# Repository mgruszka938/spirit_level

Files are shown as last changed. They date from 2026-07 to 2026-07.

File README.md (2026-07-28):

# Digital Spirit Level 

A compact, battery-powered digital level built with an STM32 microcontroller and an OLED screen. This project was developed as part of the "Sensors in Embedded Applications" course at AGH University of Science and Technology.

## Project Overview
The goal was to design a highly portable, precise digital measuring tool. The device features a USB-C port for charging, built-in Li-Ion battery support, and a three-button interface for resetting or zeroing the position. 

## Hardware & Components
The component selection prioritizes low power consumption, accuracy, and a small physical footprint.

* **Microcontroller:** STM32L433 (ARM Cortex-M4) - Picked for its low power usage and built-in FPU (Floating Point Unit) for faster angle calculations. It also runs without an external crystal oscillator, saving board space.
* **IMU Sensor:** LSM6DSO - A 6-axis accelerometer/gyroscope chosen for its high stability and low noise. Communicates over I2C.
* **Power Management:** MCP73871 - A load-sharing charge controller. It allows the device to be used normally while the Li-Ion battery is charging.
* **Display:** 0.96-inch OLED - A small, high-contrast I2C screen for the user interface.
* **Connectivity:** USB-C (charging) and SWD (programming).

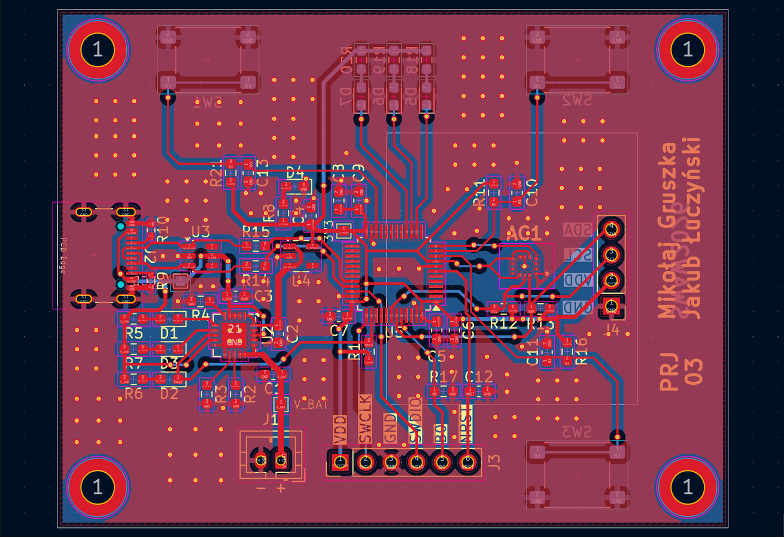
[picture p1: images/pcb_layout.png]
PCB Layout


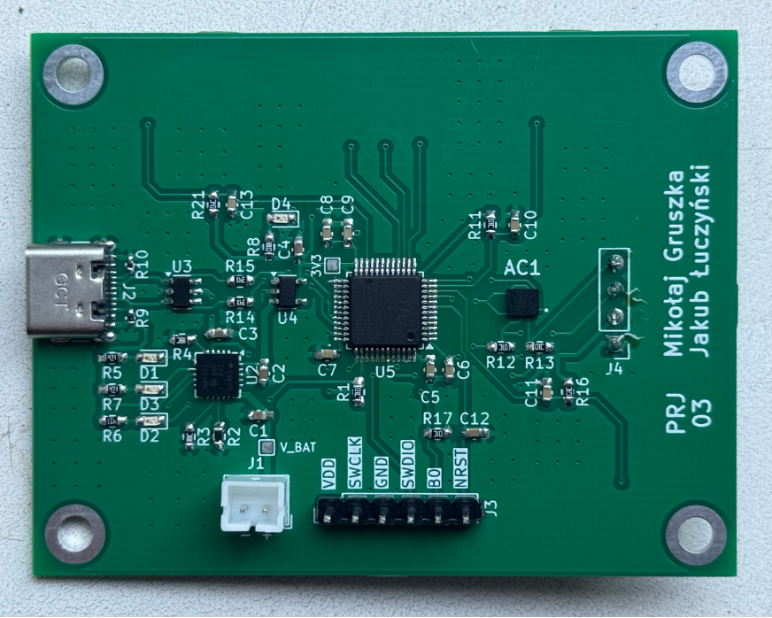
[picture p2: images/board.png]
3D Render


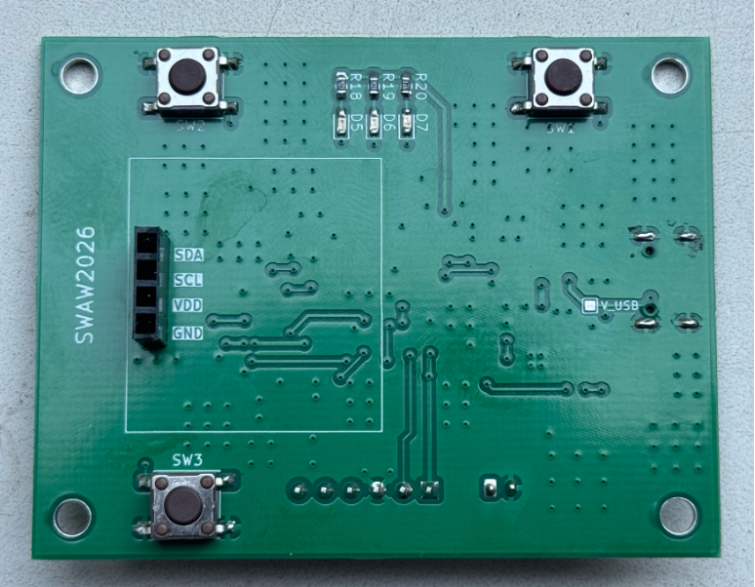
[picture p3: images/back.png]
Back


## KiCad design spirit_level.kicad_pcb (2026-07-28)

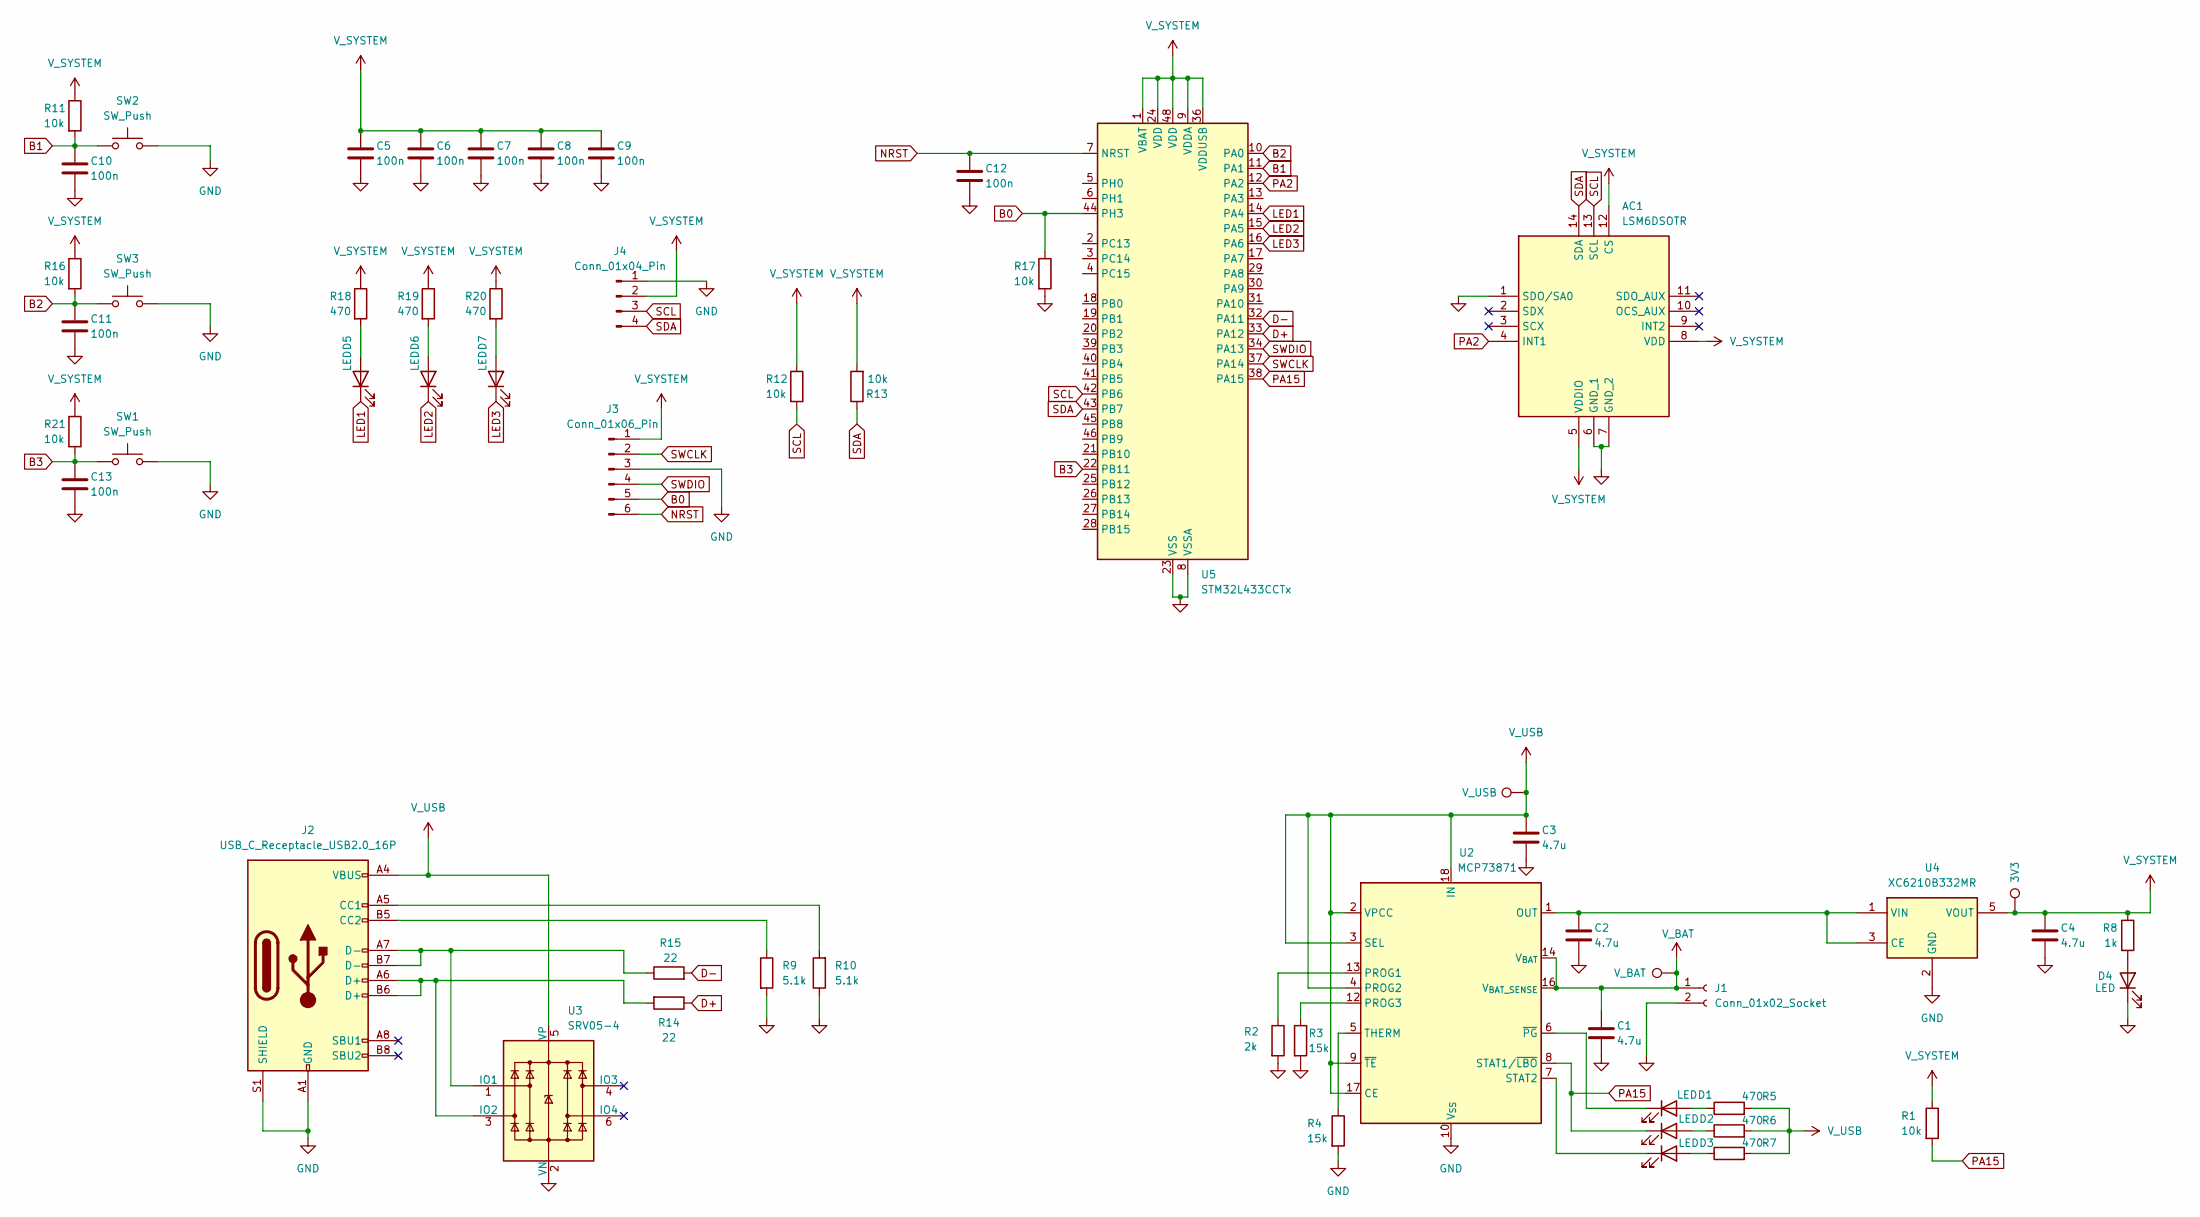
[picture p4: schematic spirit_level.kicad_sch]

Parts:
3V3: TestPoint_Pad_1.0x1.0mm
AC1: LSM6DSOTR; Mouser Part Number 511-LSM6DSOTR
C1, C2, C3, C4: 4.7u; C_0603_1608Metric_Pad1.08x0.95mm_HandSolder
C5, C6, C7, C8, C9, C10, C11, C12, C13: 100n; C_0603_1608Metric_Pad1.08x0.95mm_HandSolder
D1, D2, D3, D4, D5, D6, D7: LED; D_0603_1608Metric_Pad1.05x0.95mm_HandSolder
J1: Conn_01x02_Socket; JST_PH_B2B-PH-K_1x02_P2.00mm_Vertical
J2: USB_C_Receptacle_USB2.0_16P; USB_C_Receptacle_GCT_USB4105-xx-A_16P_TopMnt_Horizontal
J3: Conn_01x06_Pin; PinHeader_1x06_P2.54mm_Vertical
J4: Conn_01x04_Pin; PinHeader_1x04_P2.54mm_Vertical
R1, R11, R12, R13, R16, R17, R21: 10k; R_0603_1608Metric_Pad0.98x0.95mm_HandSolder
R2: 2k; R_0603_1608Metric_Pad0.98x0.95mm_HandSolder
R3, R4: 15k; R_0603_1608Metric_Pad0.98x0.95mm_HandSolder
R5, R6, R7, R18, R19, R20: 470; R_0603_1608Metric_Pad0.98x0.95mm_HandSolder
R8: 1k; R_0603_1608Metric_Pad0.98x0.95mm_HandSolder
R9, R10: 5.1k; R_0402_1005Metric_Pad0.72x0.64mm_HandSolder
R14, R15: 22; R_0603_1608Metric_Pad0.98x0.95mm_HandSolder
SW1, SW2, SW3: SW_Push; SW_SPST_PTS645Sx43SMTR92
U2: MCP73871; QFN-20-1EP_4x4mm_P0.5mm_EP2.5x2.5mm
U3: SRV05-4; SOT-23-6
U4: XC6210B332MR; SOT-23-5
U5: STM32L433CCTx; LQFP-48_7x7mm_P0.5mm
V_BAT: TestPoint_Pad_1.0x1.0mm
V_USB: TestPoint_Pad_1.0x1.0mm

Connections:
B0: J3.5, R17.1, U5.44 (PH3)
B1: C10.1, R11.2, SW2.1, U5.11 (PA1)
B2: C11.1, R16.2, SW3.1, U5.10 (PA0)
B3: C13.1, R21.2, SW1.1, U5.22 (PB11)
D+: R14.1, U5.33 (PA12)
D-: R15.2, U5.32 (PA11)
GND: AC1.1 (SDO/SA0), AC1.6 (GND_1), AC1.7 (GND_2), C1.2, C2.2, C3.2, C4.2, C5.2, C6.2, C7.2, C8.2, C9.2, C10.2, C11.2, C12.2, C13.2, D4.1 (K), J1.2, J2.A1 (GND), J2.A12 (GND), J2.B1 (GND), J2.B12 (GND), J2.S1 (SHIELD), J3.3, J4.1, R2.2, R3.2, R4.2, R9.2, R10.1, R17.2, SW1.2, SW2.2, SW3.2, U2.10 (V_{SS}), U2.11 (V_{SS}), U2.21 (V_{SS}), U3.2 (VN), U4.2 (GND), U5.8 (VSSA), U5.23 (VSS), U5.35 (VSS), U5.47 (VSS)
LED1: D5.1 (K), U5.14 (PA4)
LED2: D6.1 (K), U5.15 (PA5)
LED3: D7.1 (K), U5.16 (PA6)
NRST: C12.1, J3.6, U5.7 (NRST)
unnamed: D1.2 (A), R5.1
unnamed: D1.1 (K), U2.6 (~PG)
unnamed: D2.2 (A), R6.1
unnamed: D3.2 (A), R7.1
unnamed: D3.1 (K), U2.7 (STAT2)
unnamed: D4.2 (A), R8.2
unnamed: D5.2 (A), R18.2
unnamed: D6.2 (A), R19.2
unnamed: D7.2 (A), R20.2
unnamed: J2.A5 (CC1), R10.2
unnamed: J2.B5 (CC2), R9.1
unnamed: R2.1, U2.13 (PROG1)
unnamed: R3.1, U2.12 (PROG3)
unnamed: R4.1, U2.5 (THERM)
unnamed: J2.A7 (D-), J2.B7 (D-), R15.1, U3.1 (IO1)
unnamed: J2.A6 (D+), J2.B6 (D+), R14.2, U3.3 (IO2)
unnamed: C2.1, U2.1 (OUT), U2.20 (OUT), U4.1 (VIN), U4.3 (CE)
PA2: AC1.4 (INT1), U5.12 (PA2)
PA15: D2.1 (K), R1.2, U2.8 (STAT1/~LBO), U5.38 (PA15)
SCL: AC1.13 (SCL), J4.3, R12.2, U5.42 (PB6)
SDA: AC1.14 (SDA), J4.4, R13.1, U5.43 (PB7)
SWCLK: J3.2, U5.37 (PA14)
SWDIO: J3.4, U5.34 (PA13)
V_BAT: C1.1, J1.1, U2.14 (V_{BAT}), U2.15 (V_{BAT}), U2.16 (V_{BAT_SENSE}), V_BAT.1
V_SYSTEM: 3V3.1, AC1.5 (VDDIO), AC1.8 (VDD), AC1.12 (CS), C4.1, C5.1, C6.1, C7.1, C8.1, C9.1, J3.1, J4.2, R1.1, R8.1, R11.1, R12.1, R13.2, R16.1, R18.1, R19.1, R20.1, R21.1, U4.5 (VOUT), U5.1 (VBAT), U5.9 (VDDA), U5.24 (VDD), U5.36 (VDDUSB), U5.48 (VDD)
V_USB: C3.1, J2.A4 (VBUS), J2.A9 (VBUS), J2.B4 (VBUS), J2.B9 (VBUS), R5.2, R6.2, R7.2, U2.2 (VPCC), U2.3 (SEL), U2.4 (PROG2), U2.9 (~TE), U2.17 (CE), U2.18 (IN), U2.19 (IN), U3.5 (VP), V_USB.1

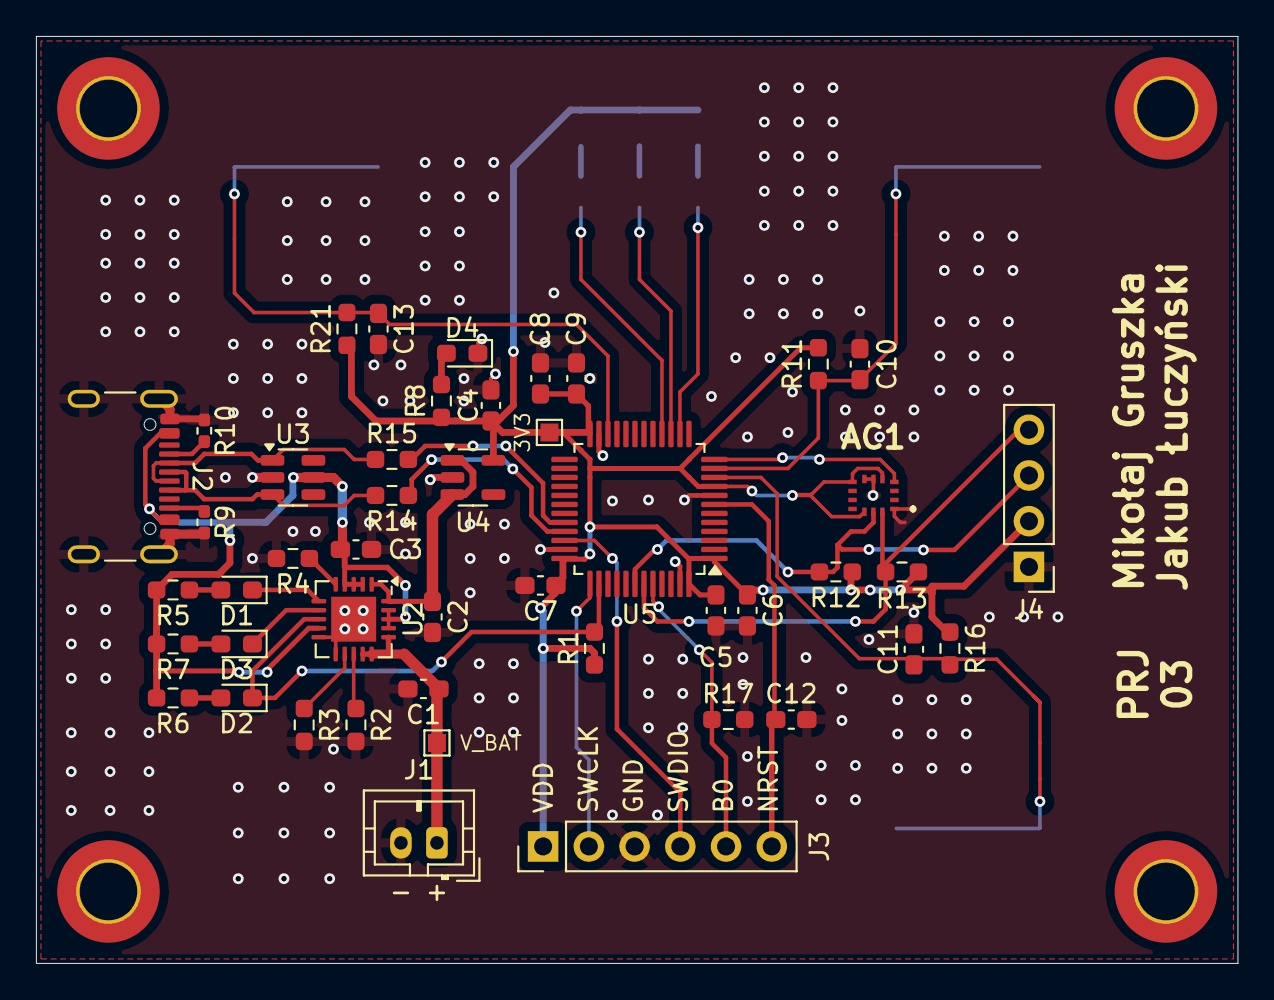
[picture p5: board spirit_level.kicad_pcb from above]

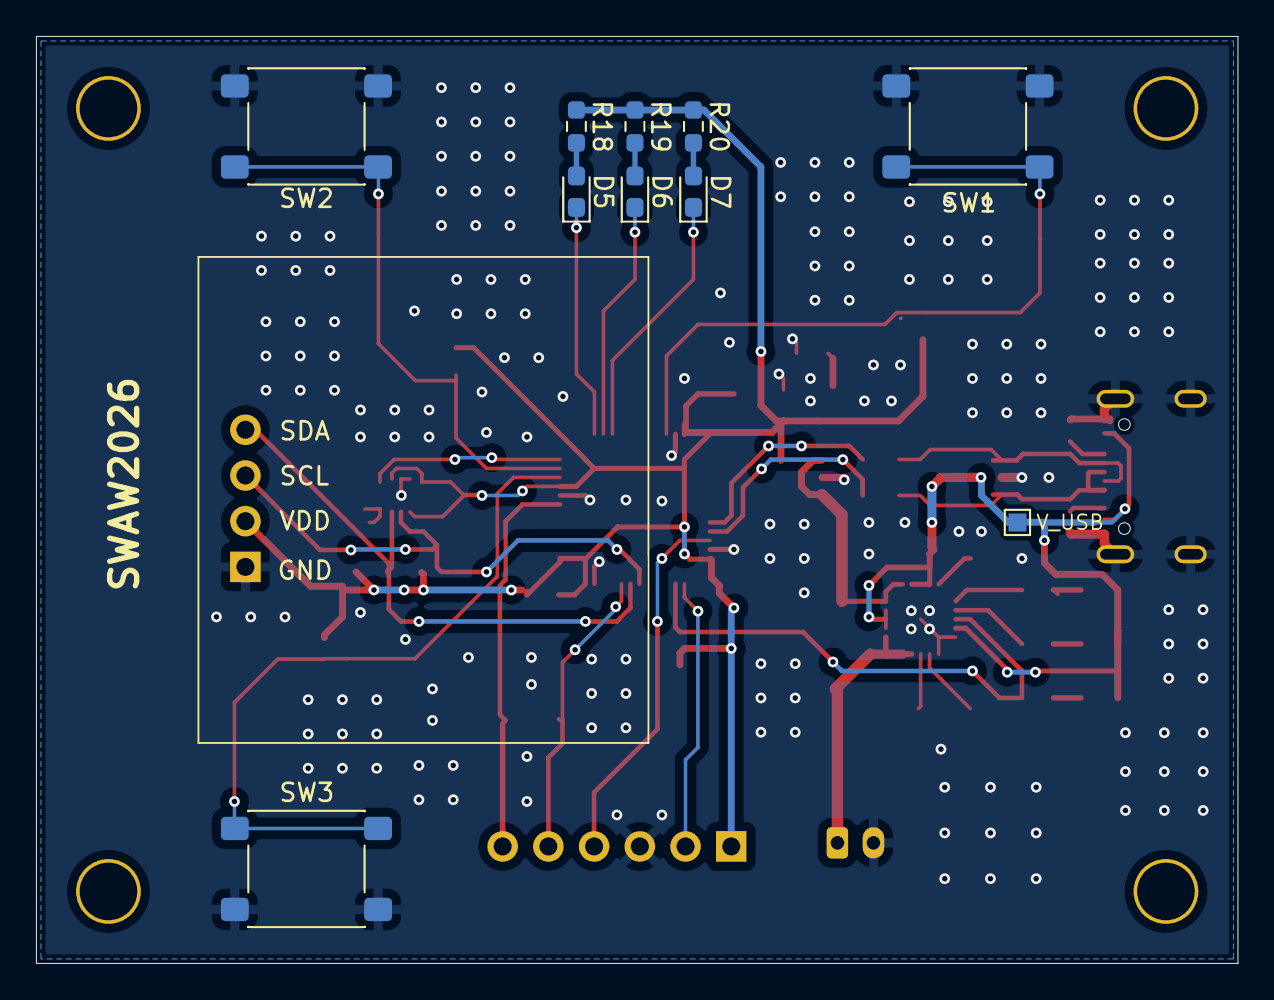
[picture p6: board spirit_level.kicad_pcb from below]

Board: 2 copper layers, 66.8 x 51.5 mm, 56 parts (10 on the bottom side), 37 nets.
